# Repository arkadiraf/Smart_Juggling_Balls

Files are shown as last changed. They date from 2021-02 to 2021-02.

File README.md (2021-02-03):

# Smart Juggling Balls
Smart Juggling Balls is a project of mine which consists of 3 basic modules: 
arduino pro mini (compatible) MPU 6050 and nrf24
and a bunch of LEDS of course :)
The files I publish include the PCB manufacturing Gerber files
STL files for the casing (ment for 3d printing)
and some code I wrote.
The idea is to have colorful and happy juggling balls which can change lightning based on the sensor readings 
and remote maniputations communicating via nrf24.

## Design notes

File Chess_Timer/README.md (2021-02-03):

# Chess Timer
Wireless chess clock, Who needs buttons when you can shake a ball :)
More info is available at: https://hackaday.io/project/7430-chess-timer
Video: https://youtu.be/bdC0Rcd7P3E

<br /><span xmlns:dct="http://purl.org/dc/terms/" property="dct:title">Chess_Timer</span> is licensed under a <a rel="license" href="http://creativecommons.org/licenses/by-nc-sa/4.0/">Creative Commons Attribution-NonCommercial-ShareAlike 4.0 International License</a>.

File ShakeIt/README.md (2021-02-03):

# ShakeIt
Shake It is an interactive art exhibition, which is based on my Smart juggling balls and a 3d printed lamp stand filled with LED`s. Shake It was developed for the Jerusalem mini maker faire. The art exhibition is intended to demonstrate light color mixing to children and then reward them with an interactive light game. 

<br /><span xmlns:dct="http://purl.org/dc/terms/" property="dct:title">ShakeIt</span> is licensed under a <a rel="license" href="http://creativecommons.org/licenses/by-nc-sa/4.0/">Creative Commons Attribution-NonCommercial-ShareAlike 4.0 International License</a>.

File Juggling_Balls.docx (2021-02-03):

Smart Juggling Balls: https://youtu.be/MuF92wXwjuk

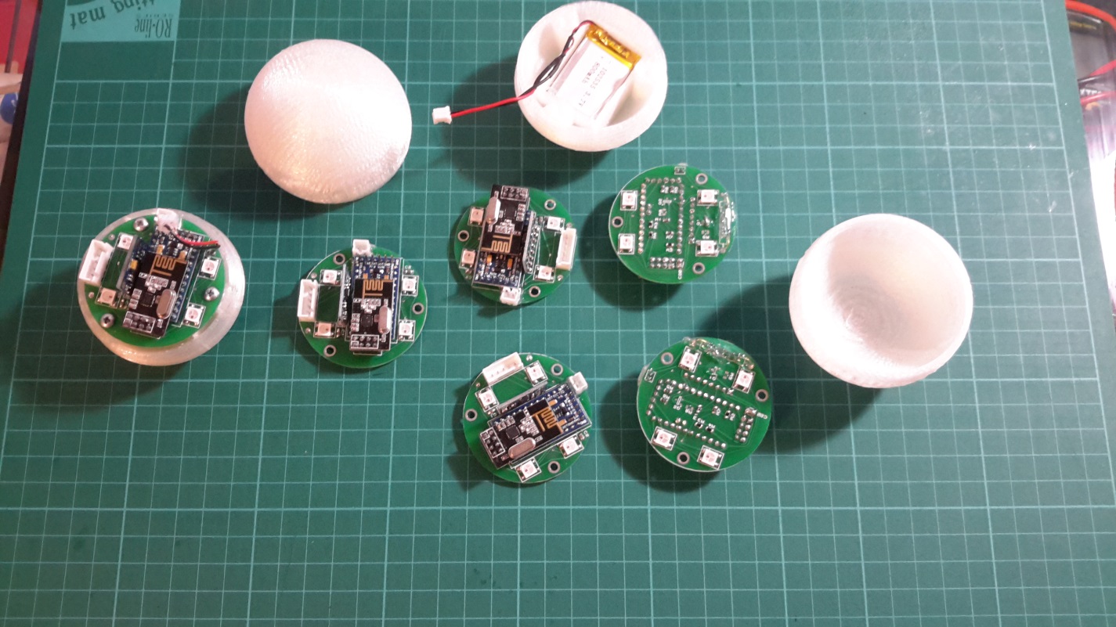
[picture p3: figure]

This is my version for smart juggling balls, the files I share include PCB Circuit manufacture files (Gerber)

STL models for the casing, and codes (currently Test code).

It is possible to assemble the juggling balls using a prototype PCB such as: https://www.sparkfun.com/products/8810 my first iterations were based on the same prototype board and later the PCB was design based on the physical dimensions of the board.

The circuit itself can be ordered from SeeeStudio http://www.seeedstudio.com/service/index.php?r=pcb

Just upload the Attached zip in Circuit→JB_Gerber.zip and order a standard 2 layer pcb. (Schematics are available in Circuit→Juggling_Balls.PDF

STL files for the casing are available in STL→Juggling_Maker_Faire

There are 2 versions one is a bit thicker.

All parts and links are available in Juggling_Balls_Bom.xlsx

Some notes on assembling:

Currently the power circuit (Transistor and mosfet) weren`t tested out,I use a wire to short the mosfet and use the connected pin (D8) as a magnet detector through the reed switch.

In one of the batches the holes for the arduino board came a bit tight so I was required to drill wider and then solder the pins for the arduino model from both sides of the pcb.

The Nrf model pins are needed to be cut a bit and the plastics removed so the NRF model will sit flat on the 2x4 header.

The circuit is design for the arduino compatible models available on ebay, such that the pinout for the FTDI is as in the image: (alternatively it is possible to use a different arduino version without soldering the FTDI headers to the pcb board, in that case the 5 pin connector will not be connected to the board DTR).

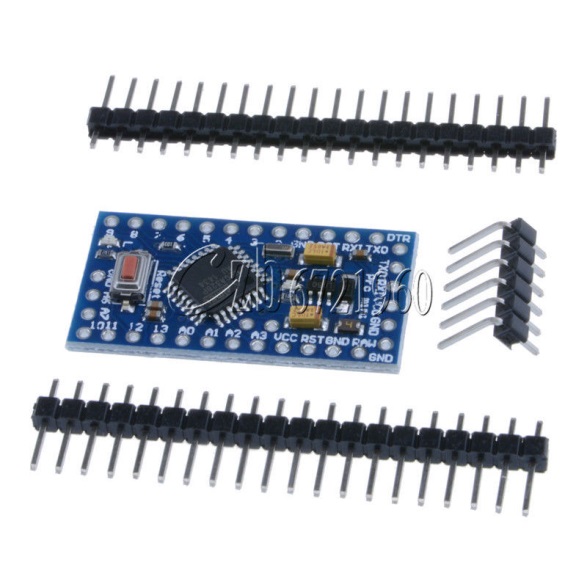
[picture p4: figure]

The direction of the SMD RGB LEDS such that the ‘cut’ corner of the LED first in the small Square drawn on the PCB.

All Resistors and capacitors aren`t Solid science, feel free to make variations, I myself solder a 1 uF capacitor instead the 47 uF and use 10kOhm resistors instead the 47kOhm

Note the correct direction for the Pin headers

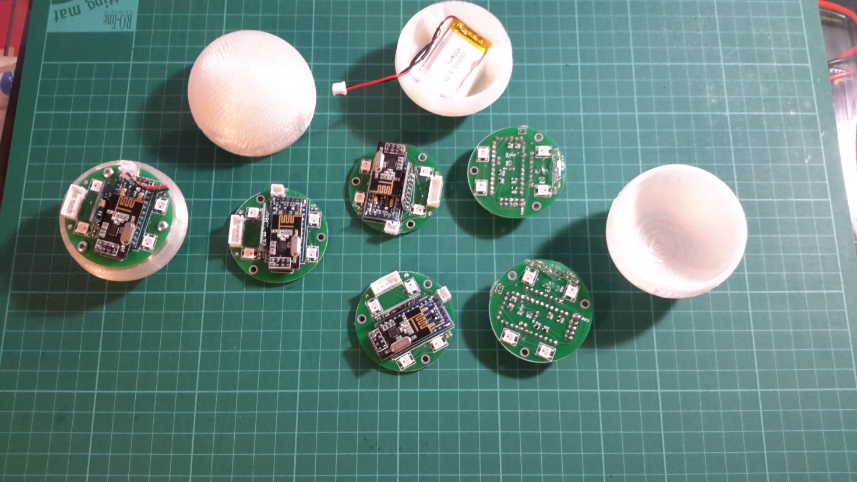
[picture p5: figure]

Enjoy.

Thanks to Eugene: http://techno-mind.ru/ for helping with the initial PCB design for manufacturing.

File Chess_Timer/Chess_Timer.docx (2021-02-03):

Chess Timer (https://hackaday.io/project/7430-chess-timer)

Wireless chess clock, Who needs buttons when you can shake a ball :)

Wirelessly controlled chess clock, to save the motion of pressing a button: you save time, you save energy, and it looks cool... Just kidding.

Recently i have joined a chess club at the google campus meetups, and as fitting for a meetup at the google campus you need to make something different. So figuring that i have already made a cool setup with my "Smart Juggling Balls": (https://hackaday.io/project/5466-smart-juggling-balls), and using the concept of interactive game of my other project, "ShakeIt" (https://hackaday.io/project/6039-shakeit). I have ended up with my current design of a chess clock.

As you can guess already, you shake the ball instead pressing the regular buttons off the clock. And because buying a chess clock just to hack it, is a little expensive i have decided to make my own design of a chess clock. (actually i think hacking a standard chess clock would have been a cheaper setup, but definitely much less cool).

So for my own design i have decided to go for a different time indication by using two digitally addressable LED rings (each ring with 16 pixels). and to wrap it all up ended up with a Lizard`s \ Robot`s Head for the clock, as you can see in the images :).

So basically i have ended up with 2 juggling balls and a lizard`s head, when you shake a ball the opponents time is starting to get down, The amount of LED`s on, indicates how much time is left. and while it is your turn the ball is also colored, RED and Blue for each opponent, and Green for when it`s not your turn. (The video demonstrates it better).

For setting the time, Displaying the exact time left, and other setting`s i am using bluetooth module in the lizard`s head to communicate with a standard smartphone app wich streams data over bluetooth.

All of the sources (Codes, PCB, STL`s) are available on Github and on Thingiverse. You are welcome to make your own wireless chess clock.

Enjoy.

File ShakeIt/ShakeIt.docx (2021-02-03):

# ShakeIt

# Interactive Art Exhibition

ShakeIt is an interactive art exhibition, which is based on my Smart juggling balls and a 3d printed lamp stand filled with LED`s. ShakeIt was developed for the Jerusalem mini maker faire. The art exhibition is intended to demonstrate light color mixing to children and then reward them with an interactive light game.

Operation:

First each kid is handed a smart ball, with a predefined color (Red, Green, Blue) when the ball is shaken (Accelerometer) the light inside the ball becomes stronger (RGB LED`s). The lamp stand is used as a mixer, it communicates with the balls and receives the value of how strong the light inside each of the smart balls mixing them and generating the mixed color.

The kids are then requested to shake the ball in sequence than in pairs generating all sorts of mixes and understanding how light is mixed and what colors are generated from the basic lights (Red, Green, Blue).

After that the participants get to play an interactive game, the game consists the same smart balls, and the light stand, but instead of just mixing the light the stand generates patterns based on how strong the balls are shaken. At first the light is just filling up the stand but then each color starting to eat the next one until only one color remains and the winner is declared. (see video)

Technical information:

The smart juggling balls description can be found here: https://github.com/arkadiraf/Juggling_Balls_Public , or on my Hackaday project page: https://hackaday.io/project/5466-smart-juggling-balls.

The Light stand consists of Arduino nano (compatible), Nrf24L01+ with SMA Antenna, Dc Dc converter to step down from 6-12 volts to 5 volts (meant to be used with external 12V power supply, or 2S lipo battery), Digital Addresable LED`s in a strip of 60 Leds/Meter with a total of 74 LED`s, Bluetooth module HC-05. Some capacitors, 3.3 voltage regulator and a schottky diode3A for reverse voltage protection. The arduino Nano is fed directly from the power supply (through the diode) and the DC DC converter is used for the LED strip. Currently I am using a pcb I designed with traces for the NRF module, Arduino nano (compatible) and the 3.3V regulator, around which I constructed the rest of the circuit). The files of the PCB are available on GitHub. The StL files for the lamp stand are also available on GitHub including both the codes for the smart balls and the lamp.

Notes:

I am using the Accelerometer to measure how strong the ball is shaken by measuring the acceleration and filtering the results with a simple digital LPF Filter with a time constant of a few seconds.

The lamp stand uses the NRF module to communicate with the Smart balls, and the Bluetooth module is used to communicate with a Smartphone using it as an interface and changing the operation modes.

The code for the system is designed to interact with up to 15 Smart balls, starting by scanning which balls are active and then using a simple protocol to communicate with each of the active balls by sending a request for data and waiting for a response.

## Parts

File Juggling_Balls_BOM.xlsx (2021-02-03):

 | Juggling Balls Parts
Item |  | Link
1 circuit PCB or Prototype round PCB: |  | https://www.sparkfun.com/products/8810
Casing (3d Printed) |  | STL Files
Arduino Compatible pro mini |  | http://www.ebay.com/itm/131091305008?_trksid=p2060778.m2749.l2649&ssPageName=STRK%3AMEBIDX%3AIT
MPU 6050 |  | http://www.ebay.com/itm/161267559751?_trksid=p2060778.m2749.l2649&ssPageName=STRK%3AMEBIDX%3AIT
NRF24L01 |  | http://www.ebay.com/itm/140729183185?_trksid=p2060778.m2749.l2649&ssPageName=STRK%3AMEBIDX%3AIT
ReedSwitch |  | http://www.ebay.com/itm/161267559751?_trksid=p2060778.m2749.l2649&ssPageName=STRK%3AMEBIDX%3AIT
Li-Ion Battery |  | http://www.aliexpress.com/snapshot/6526903112.html?orderId=66147013510053
SMD Parts: | SeeedStudio | http://www.seeedstudio.com/depot/OPLopen-parts-library-catalog-c-136_138/?ref=side
WS2812b LED | SKU: 800052001 | http://www.seeedstudio.com/depot/WS2812B-RGB-LED-with-Integrated-Driver-Chip-10-PCs-pack-p-1675.html
Mosfet |  | SMD MOSFET P-CH -8V -4.1A(0440210P1)
Transistor |  | SMD Transistors NPN 25V-500mA(0400000P1)
Resistors |  | SMD RES 10K-5%-1/8W(301010304)
 |  | SMD RES 47K-1%-1/8W(301010388)
 |  | SMD RES 220R-5%-1/8W(301010315
 |  | SMD RES 1K-5%-1/8W(301010311)
Capacitors |  | SMD CAP Ceramic 100nF-50V-10%-X7R;(302010165)
 |  | SMD CAP Ceramic 1uF-25V-10%-X7R(0100440P1)
Connectors |  | DIP JST 2P-2.0(320110049)
DIP JST 5P 2.5 |  | http://www.ebay.com/itm/10-kits-XH2-54mm-5pin-JST-Connector-plug-Male-Female-Crimps-DIP-5P-/331376224432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
DIP 8P 2x4 Female header 2.54 |  | http://www.ebay.com/itm/10PCS-2x4-Pin-8P-2-54mm-Double-Row-Female-Straight-Header-Pitch-Socket-Pin-Strip-/310727244114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
Alternative sensor:
MPU 9150 |  | http://www.ebay.com/itm/161096342893?_trksid=p2060778.m2749.l2649&ssPageName=STRK%3AMEBIDX%3AIT

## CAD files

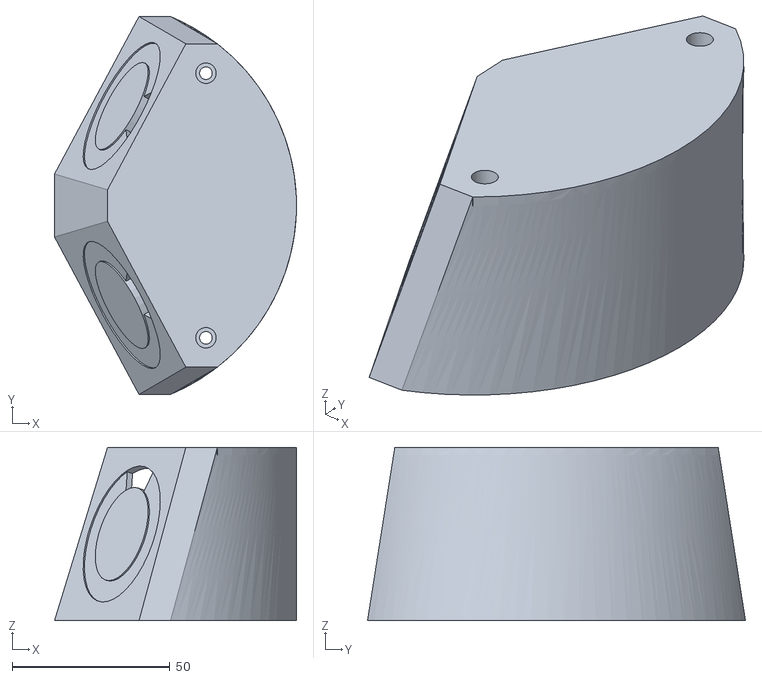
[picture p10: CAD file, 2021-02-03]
Chess_Timer/STL/Timer_Box_1.STL
76.8 x 120.0 x 55.0

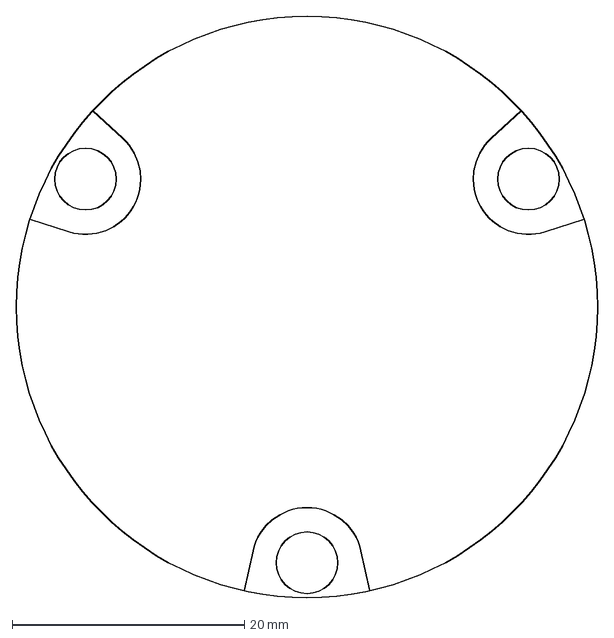
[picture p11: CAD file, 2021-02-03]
Electronics/EduBall_V1.1 - forgotten version/EduBall_Flex.DXF
50.0 x 50.0 mm

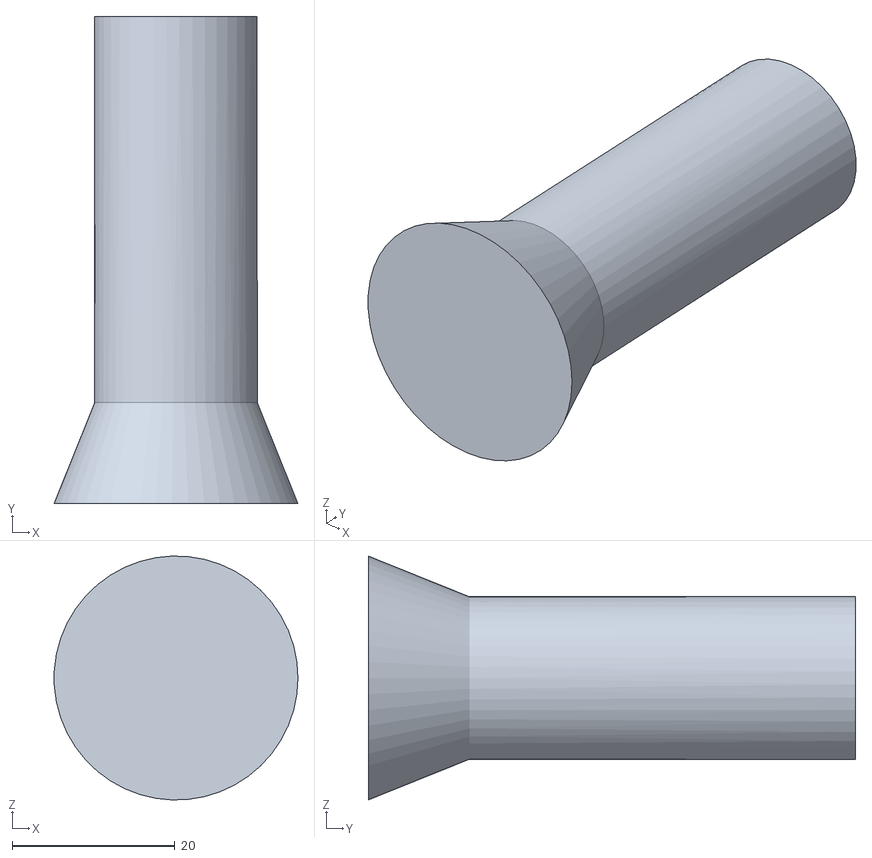
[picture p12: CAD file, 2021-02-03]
ShakeIt/STL/Sensor_Holder.STL
30.0 x 59.9 x 30.0

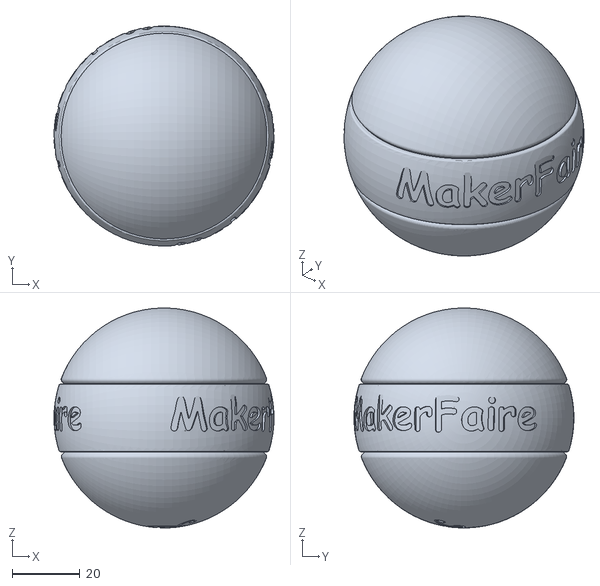
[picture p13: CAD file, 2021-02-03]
STL/Juggling_MakerFaire.STL
65.0 x 65.0 x 64.9

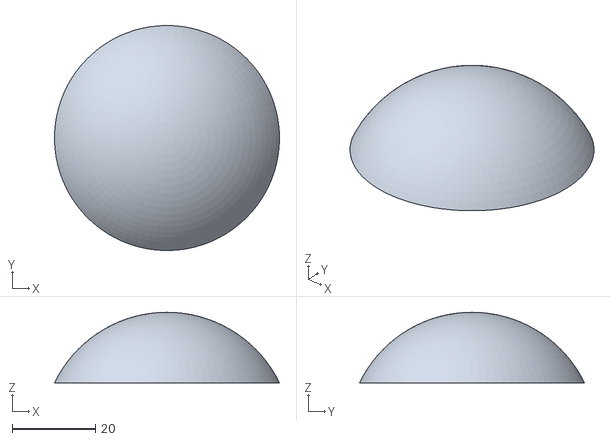
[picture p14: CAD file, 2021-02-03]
Chess_Timer/STL/Eye_Cover_Flat.stl
54.0 x 54.0 x 16.9

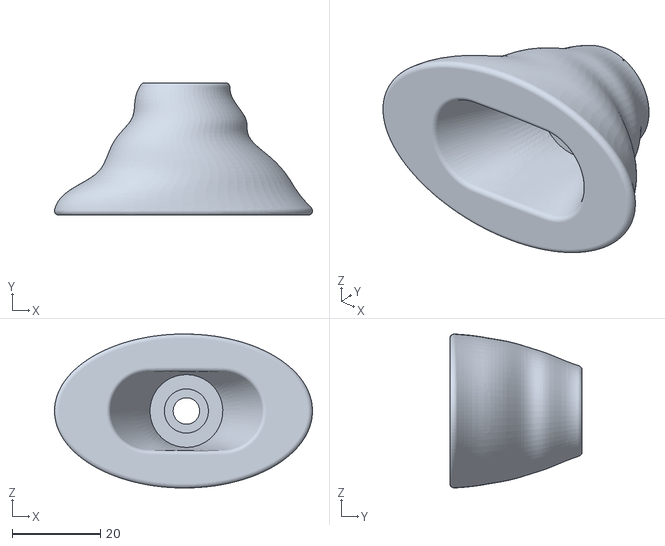
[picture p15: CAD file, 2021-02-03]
ShakeIt/STL/Magnet_Stand.STL
58.4 x 30.0 x 34.9

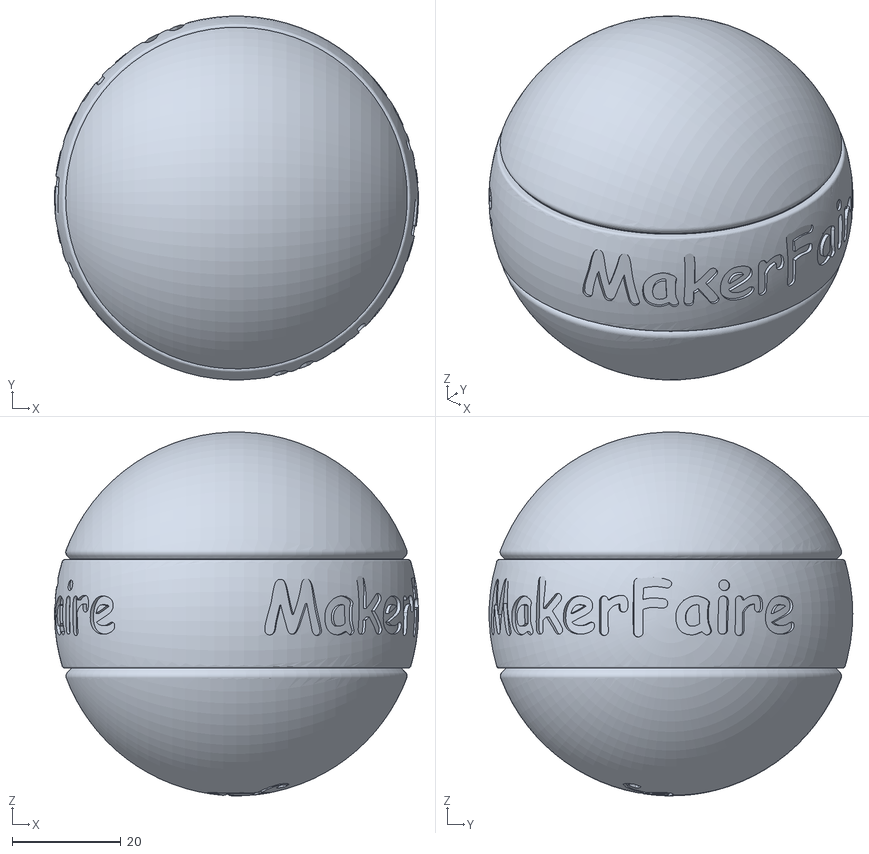
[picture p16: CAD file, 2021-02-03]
STL/Juggling_2_MakerFaire.STL
67.0 x 66.9 x 66.9

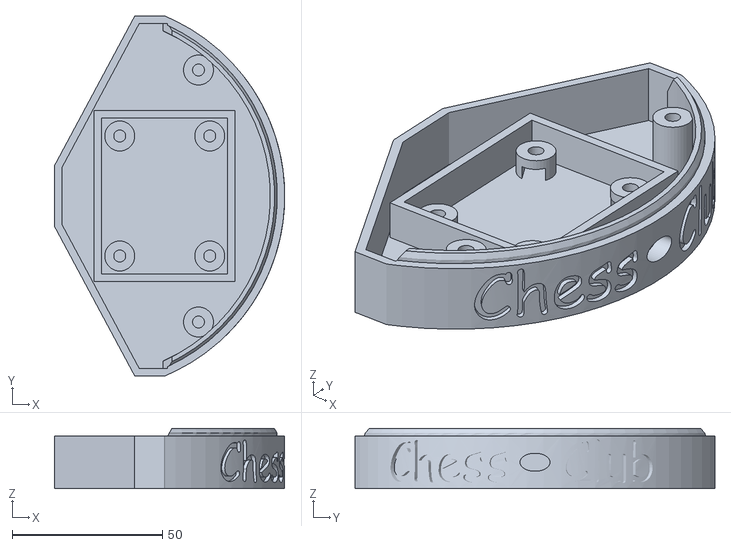
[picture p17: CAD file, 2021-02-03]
Chess_Timer/STL/Timer_Box_2.STL
76.8 x 120.0 x 20.0

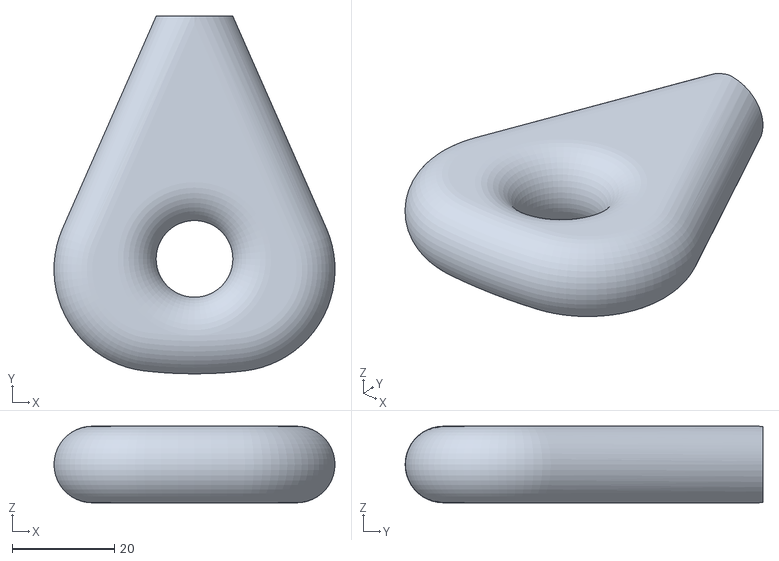
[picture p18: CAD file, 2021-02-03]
ShakeIt/STL/Magnet_Holder.STL
55.0 x 70.0 x 15.0

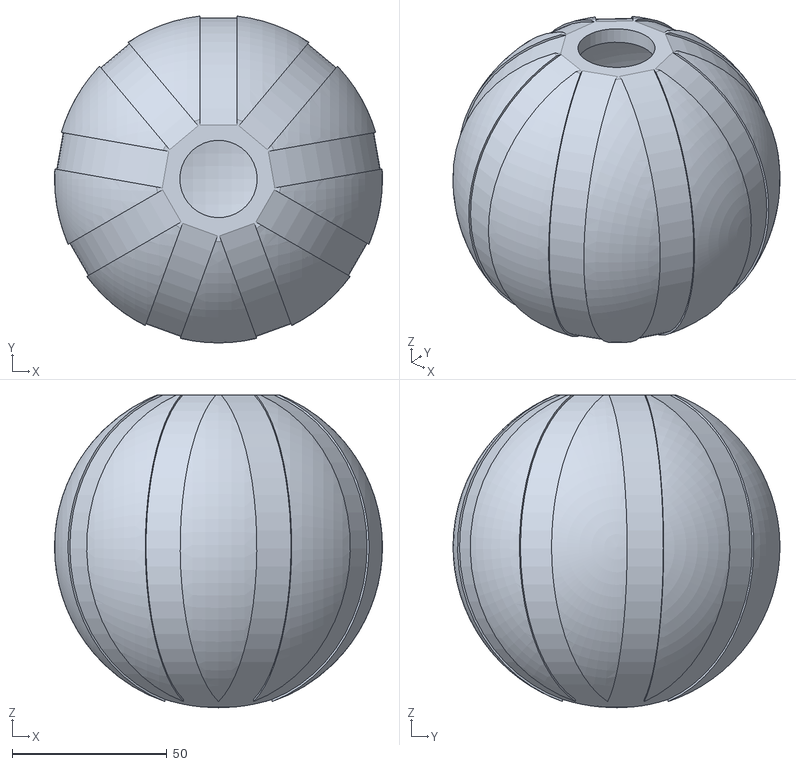
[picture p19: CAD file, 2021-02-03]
ShakeIt/STL/Led_Lamp.STL
106.0 x 105.6 x 101.0

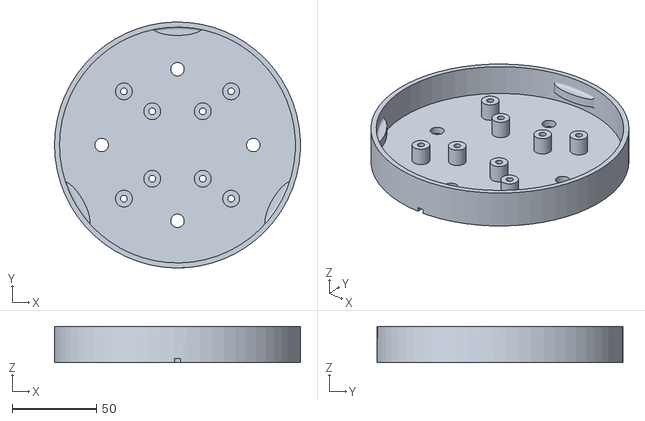
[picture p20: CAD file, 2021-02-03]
ShakeIt/STL/Lamp_Base.STL
146.0 x 146.0 x 21.5

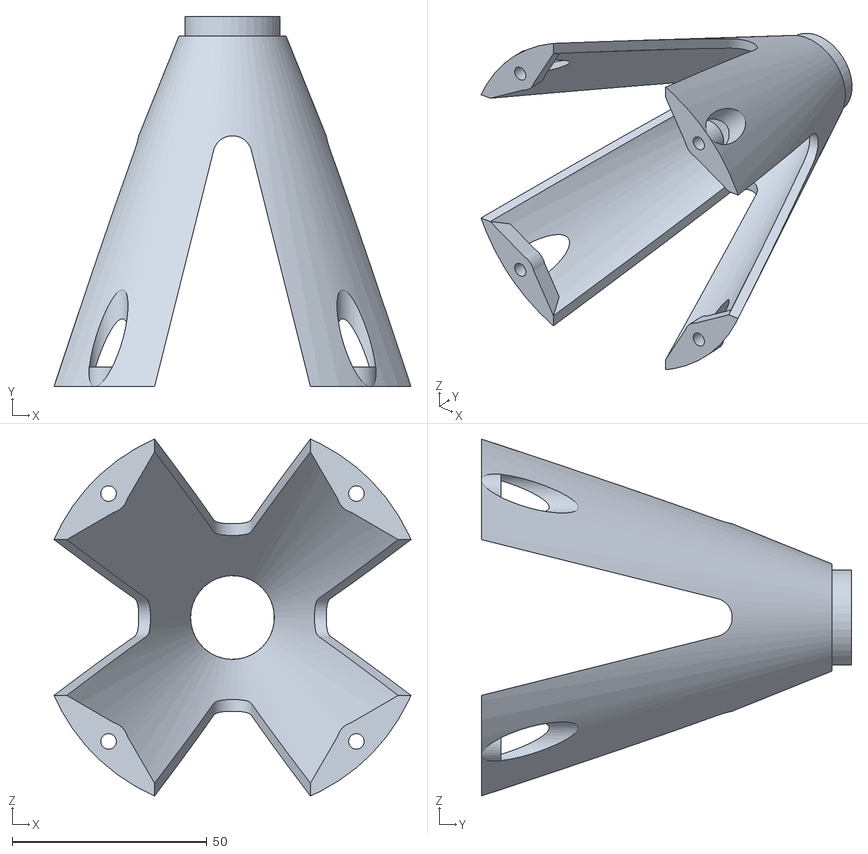
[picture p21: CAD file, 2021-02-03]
ShakeIt/STL/Lamp_Holder.STL
91.7 x 95.0 x 91.7

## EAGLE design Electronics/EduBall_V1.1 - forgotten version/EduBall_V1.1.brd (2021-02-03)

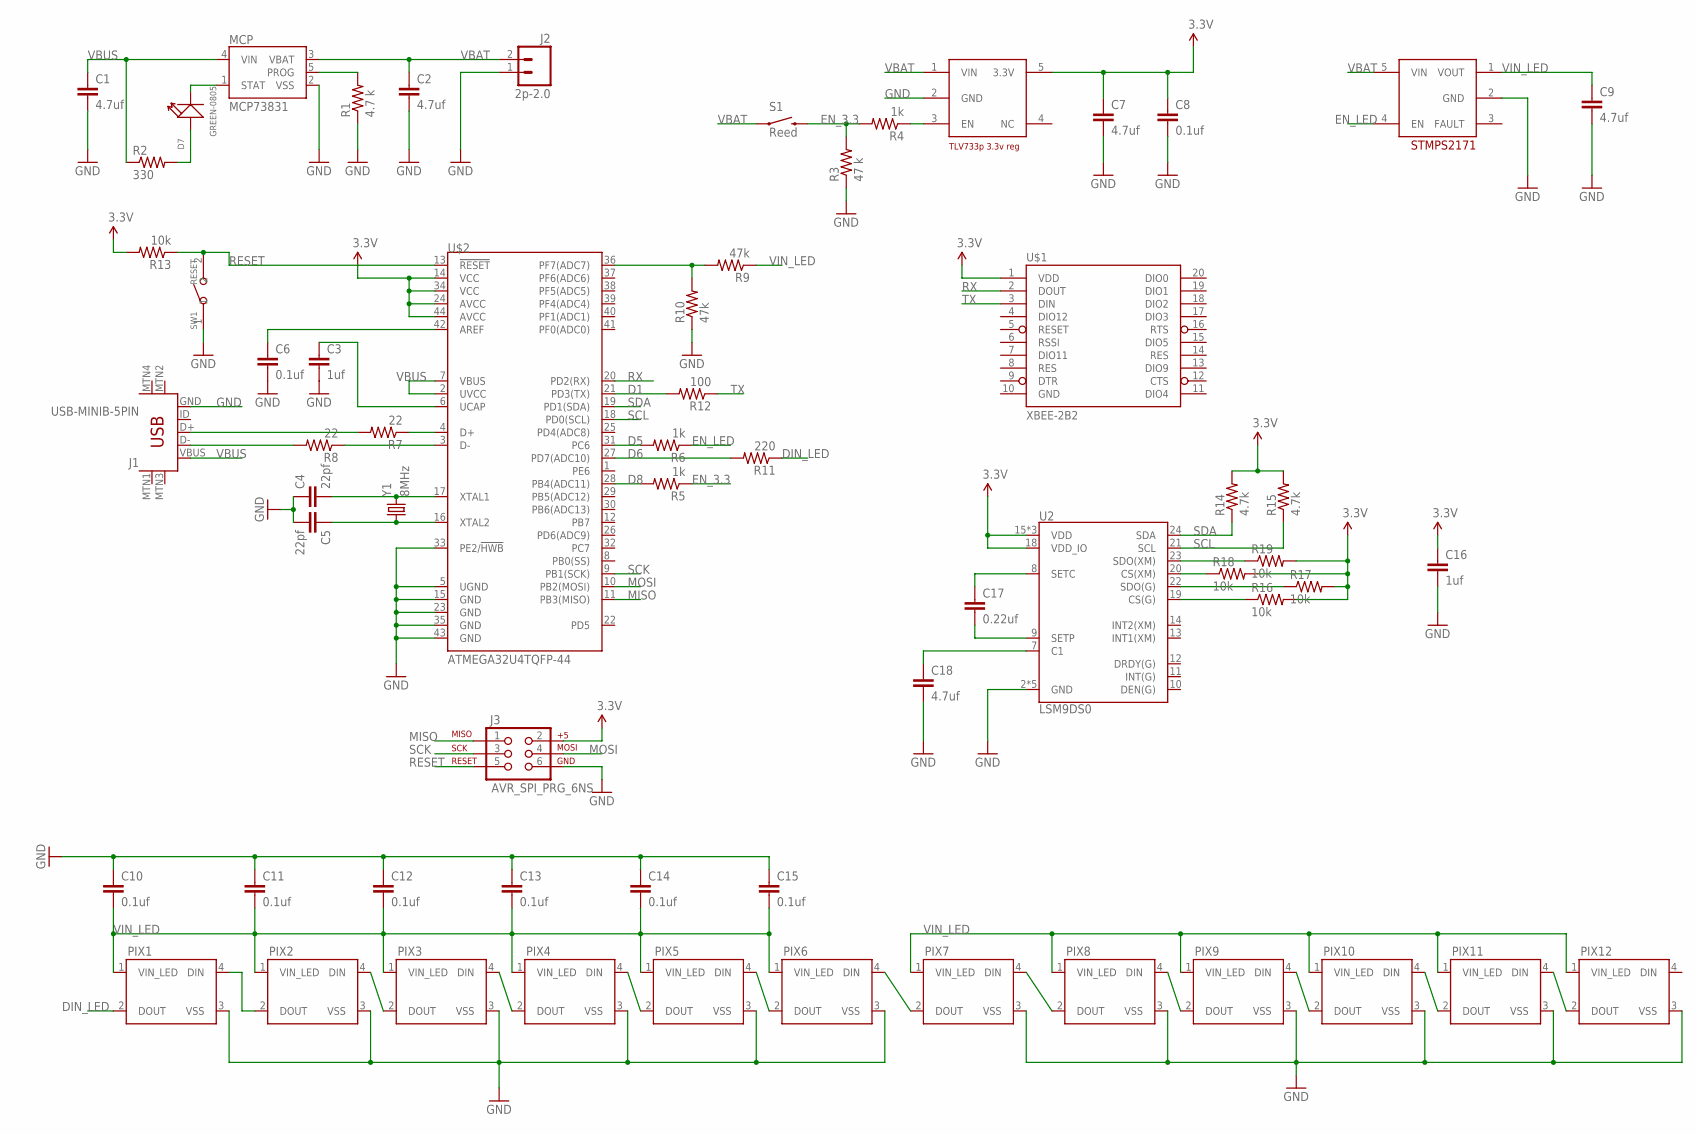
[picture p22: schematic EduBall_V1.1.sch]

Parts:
C1, C2, C7, C9, C18: 4.7uf; 0805
C3, C16: 1uf; 0805
C4, C5: 22pf; 0805
C6, C8, C10, C11, C12, C13, C14, C15: 0.1uf; 0805
C17: 0.22uf; 0805
D7: GREEN-0805; LED-0805
J1: USB-MINIB-5PIN; USB-MINIB
J2: 2p-2.0; JST-2-PTH-VERT
J3: AVR_SPI_PRG_6NS; 2X3-NS
MCP: MCP73831; SOT23-5
PIX1, PIX2, PIX3, PIX4, PIX5, PIX6, PIX7, PIX8, PIX9, PIX10, PIX11, PIX12: WS2812B
R1: 4.7 k; 0805
R2: 330; 0805
R3: 47 k; 0805
R4, R5, R6: 1k; 0805
R7, R8: 22; 0805
R9, R10: 47k; 0805
R11: 220; 0805
R12: 100; 0805
R13, R16, R17, R18, R19: 10k; 0805
R14, R15: 4.7k; 0805
S1: Reed; REED_SWITCH_PTH
STMP: STMPS2171; SOT23-5
SW1: RESET; SW2-2.6-3.0X2.5X1.2+0.4MM
TLV: TLV3333P; SOT23-5
U2: LSM9DS0; LGA-24
U$1: XBEE-2B2; XBEE-SILK
U$2: ATMEGA32U4TQFP-44; TQFP44
Y1: 8MHz; HC49US

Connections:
3.3V: C7.1, C8.1, C16.1, J3.2, R13.2, R14.2, R15.2, R16.2, R17.2, R18.2, R19.2, TLV.5 (3.3V), U2.15 (VDD), U2.16 (VDD), U2.17 (VDD), U2.18 (VDD_IO), U$1.1 (VDD), U$2.14 (VCC), U$2.24 (AVCC), U$2.34 (VCC), U$2.44 (AVCC)
D1: R12.2, U$2.21 (PD3(TX))
D5: R6.2, U$2.31 (PC6)
D6: R11.2, U$2.27 (PD7(ADC10))
D8: R5.2, U$2.28 (PB4(ADC11))
DIN_LED: PIX1.2 (DOUT), R11.1
EN_3.3: R3.2, R4.2, R5.1, S1.P$2 (2)
EN_LED: R6.1, STMP.4 (EN)
GND: C1.2, C2.2, C3.2, C4.1, C5.2, C6.2, C7.2, C8.2, C9.2, C10.1, C11.1, C12.1, C13.1, C14.1, C15.1, C16.2, C18.2, J1.GND, J2.1, J3.6, MCP.2 (VSS), PIX1.3 (VSS), PIX2.3 (VSS), PIX3.3 (VSS), PIX4.3 (VSS), PIX5.3 (VSS), PIX6.3 (VSS), PIX7.3 (VSS), PIX8.3 (VSS), PIX9.3 (VSS), PIX10.3 (VSS), PIX11.3 (VSS), PIX12.3 (VSS), R1.1, R3.1, R10.1, STMP.2 (GND), SW1.1, TLV.2 (GND), U2.2 (GND), U2.3 (GND), U2.4 (GND), U2.5 (GND), U2.6 (GND), U$1.10 (GND), U$2.5 (UGND), U$2.15 (GND), U$2.23 (GND), U$2.33 (PE2/!HWB), U$2.35 (GND), U$2.43 (GND)
MISO: J3.1, U$2.11 (PB3(MISO))
MOSI: J3.4, U$2.10 (PB2(MOSI))
unnamed: MCP.5 (PROG), R1.2
unnamed: PIX1.4 (DIN), PIX2.2 (DOUT)
unnamed: R4.1, TLV.3 (EN)
unnamed: D7.-, MCP.1 (STAT)
unnamed: D7.+, R2.2
unnamed: PIX2.4 (DIN), PIX3.2 (DOUT)
unnamed: PIX3.4 (DIN), PIX4.2 (DOUT)
unnamed: PIX4.4 (DIN), PIX5.2 (DOUT)
unnamed: PIX5.4 (DIN), PIX6.2 (DOUT)
unnamed: PIX6.4 (DIN), PIX7.2 (DOUT)
unnamed: PIX7.4 (DIN), PIX8.2 (DOUT)
unnamed: PIX8.4 (DIN), PIX9.2 (DOUT)
unnamed: PIX9.4 (DIN), PIX10.2 (DOUT)
unnamed: PIX10.4 (DIN), PIX11.2 (DOUT)
unnamed: PIX11.4 (DIN), PIX12.2 (DOUT)
unnamed: J1.D+, R7.2
unnamed: R7.1, U$2.4 (D+)
unnamed: R8.1, U$2.3 (D-)
unnamed: J1.D-, R8.2
unnamed: C3.1, U$2.6 (UCAP)
unnamed: C6.1, U$2.42 (AREF)
unnamed: C18.1, U2.7 (C1)
unnamed: C4.2, U$2.17 (XTAL1), Y1.2
unnamed: C5.1, U$2.16 (XTAL2), Y1.1
unnamed: R9.2, R10.2, U$2.36 (PF7(ADC7))
unnamed: C17.2, U2.9 (SETP)
unnamed: C17.1, U2.8 (SETC)
unnamed: R19.1, U2.23 (SDO(XM))
unnamed: R18.1, U2.20 (CS(XM))
unnamed: R17.1, U2.22 (SDO(G))
unnamed: R16.1, U2.19 (CS(G))
RESET: J3.5, R13.1, SW1.2, U$2.13 (!RESET)
RX: U$1.2 (DOUT), U$2.20 (PD2(RX))
SCK: J3.3, U$2.9 (PB1(SCK))
SCL: R15.1, U2.21 (SCL), U$2.18 (PD0(SCL))
SDA: R14.1, U2.24 (SDA), U$2.19 (PD1(SDA))
TX: R12.1, U$1.3 (DIN)
VBAT: C2.1, J2.2, MCP.3 (VBAT), S1.P$1 (1), STMP.5 (VIN), TLV.1 (VIN)
VBUS: C1.1, J1.VBUS, MCP.4 (VIN), R2.1, U$2.2 (UVCC), U$2.7 (VBUS)
VIN_LED: C9.1, C10.2, C11.2, C12.2, C13.2, C14.2, C15.2, PIX1.1 (VIN_LED), PIX2.1 (VIN_LED), PIX3.1 (VIN_LED), PIX4.1 (VIN_LED), PIX5.1 (VIN_LED), PIX6.1 (VIN_LED), PIX7.1 (VIN_LED), PIX8.1 (VIN_LED), PIX9.1 (VIN_LED), PIX10.1 (VIN_LED), PIX11.1 (VIN_LED), PIX12.1 (VIN_LED), R9.1, STMP.1 (VOUT)

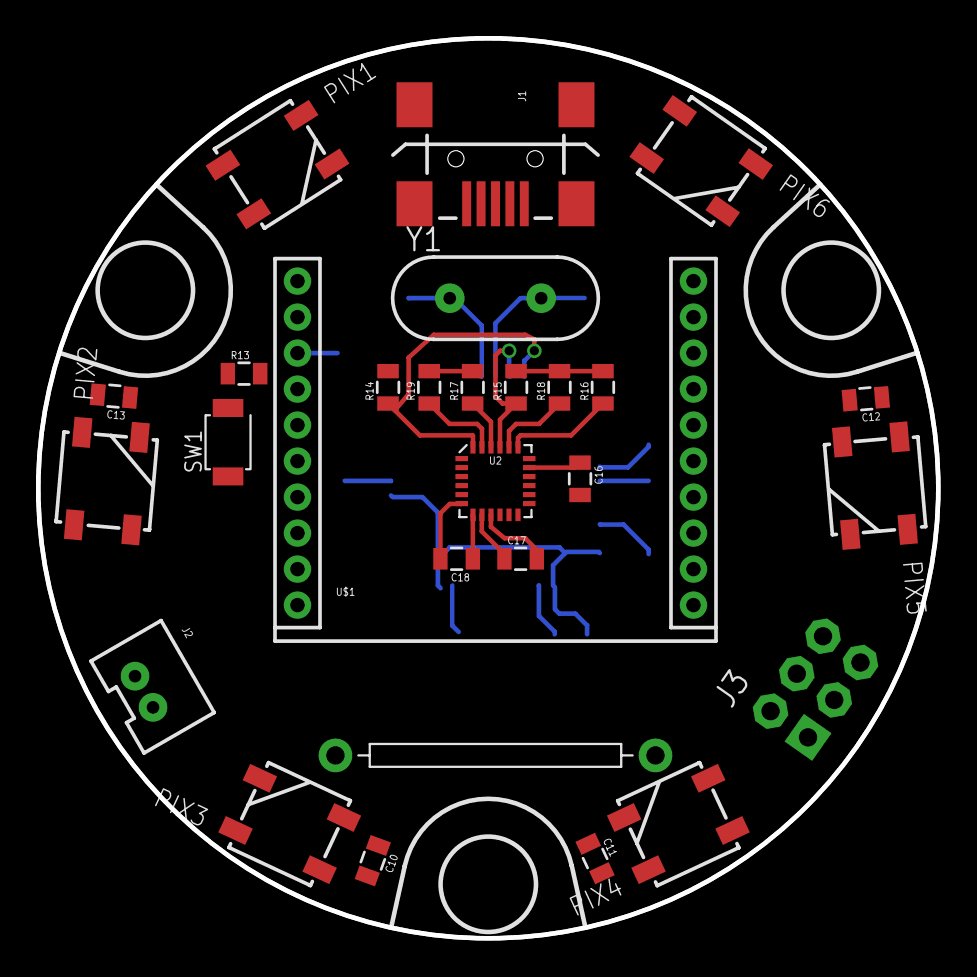
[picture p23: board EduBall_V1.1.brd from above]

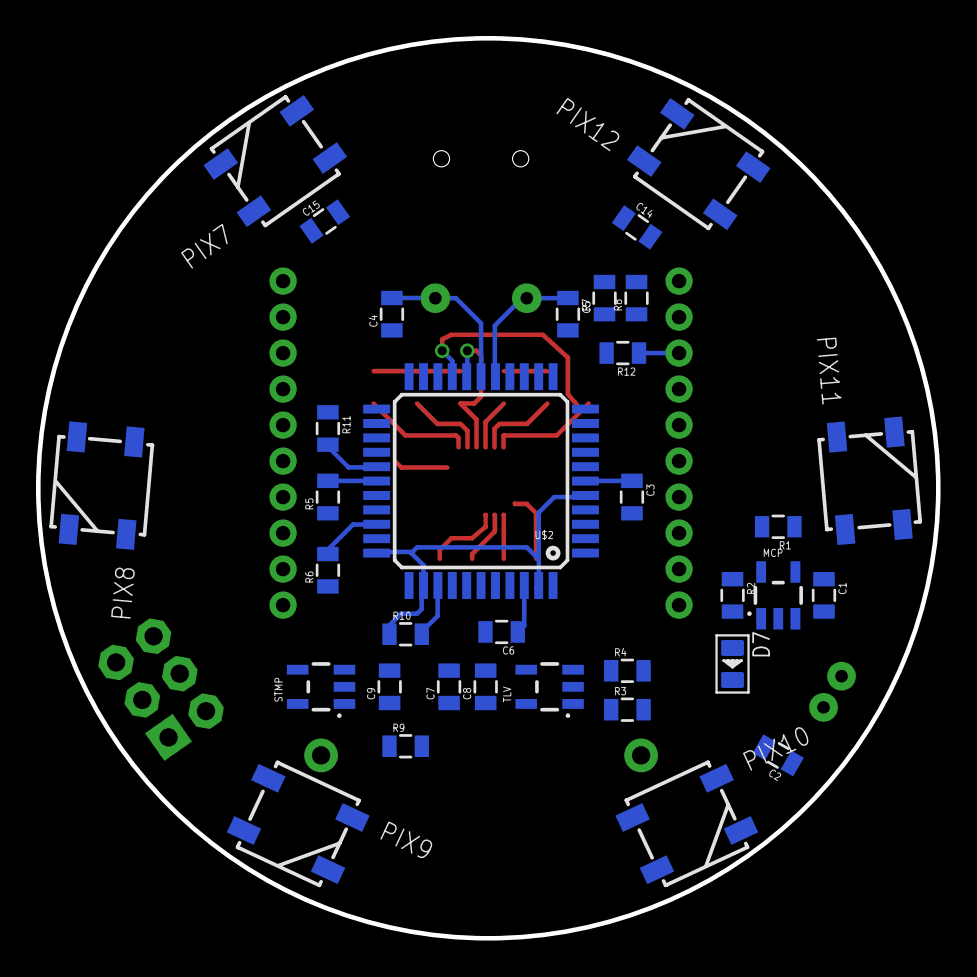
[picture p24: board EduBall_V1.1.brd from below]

Board: 2 copper layers, 50.0 x 50.0 mm, 62 parts (34 on the bottom side), 51 nets.

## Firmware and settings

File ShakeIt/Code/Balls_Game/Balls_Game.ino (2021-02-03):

// Balls_Game 21/05/2015 1:20

/* Pinout:
    Arduino 3.3V:
    A5 (SCL)-->SCL
    A4 (SDA)-->SDA
    D2-->INT DRDYG
    
    D8-->Reed Switch
    
    D6-->NeoPIxel DataIn
    
    A0-->Vraw/2
    
    D9-->CE NRF
    D10-->CSN NRF
    D13 (SCK)-->SCK NRF
    D11 (MOSI)-->MOSI NRF
    D12 (MISO)-->MISO NRF
    D3-->IRQ
    
    connector:
    Vcc--> baterry Vcc
    Dtr --> directly
    Tx --> through 1k // in order to protect from shorts
    Rx --> through 1k
    Grnd --> battery GRN
*/
#define BallNumber 13
///////////////
// libraries //
///////////////
#include <math.h>
#include <SPI.h>
#include "nRF24L01.h"
#include "RF24.h"
#include <Adafruit_NeoPixel.h>
#include "I2Cdev.h"
#include "MPU6050.h"
#include "Wire.h"

///////////////
// Variables //
///////////////

#define rad2deg 57.295

///////////////
// MPU 6050 //
///////////////

MPU6050 accelgyro;

#define MPUREADDELAY 20
// Single radio pipe address for the 2 nodes to communicate.
unsigned long MpuMillisStamp=0;

const byte INT_MPU_PIN = 2; // INT DRDYG

int16_t ax, ay, az;
int16_t gx, gy, gz;

double AcclValue[3]={0,0,0}; //in G values
double GyroValue[3]={0,0,0}; //in Degrees per second

#define SAMPLE2GACC 2048.0   // +/-16g full scale, 16 bit resolution--> 2^16/32=2048
#define SAMPLE2AGYRO 16.384  // +/-2000 Deg/Sec, 16 but tesolution--> 2^16/4000=16.384
	
////////////////////////////
// communication variable //
////////////////////////////
#define NUMPLAYERS 15
// players addresses
const uint64_t BallsAddresses[NUMPLAYERS] ={0xF3b1b3F5c3LL,0xF3b2b3F5c3LL,0xF3b3b3F5c3LL,0xF3b4b3F5c3LL,0xF3b5b3F5c3LL,0xF3b6b3F5c3LL,0xF3b7b3F5c3LL,0xF3b8b3F5c3LL,0xF3b9b3F5c3LL,0xF3bab3F5c3LL,0xF3bbb3F5c3LL,0xF3bcb3F5c3LL,0xF3bdb3F5c3LL,0xF3beb3F5c3LL,0xF3bfb3F5c3LL};
#define CommunicationDelay 100
// Single radio pipe address for the 2 nodes to communicate.
unsigned long CommunicationMillisStamp=0;

// Set up nRF24L01 radio on SPI bus plus pins 9 & 10
RF24 radio(9,10);
// Radio pipe addresses for the 2 nodes to communicate.
//const uint64_t pipes[2] = { 0xF0F0F0F0E1LL, 0xF0F0F0F0D2LL };
const uint64_t Txpipes[2] ={0xb3F3F3b3b5LL,0xb3F3F3b3b7LL};
const uint64_t Rxpipes =BallsAddresses[BallNumber];
#define NTWIDN 0xF3F3F3

/////////////
// Battery //
/////////////
double Vbaterry=3.7;
#define VBATTERY_PIN A0
#define ADC2VBAT 163.0 // Convert ADC reading to voltage, VBatt*10/57=Vref/ADC_Res Vref=1.1v ADC_Res=1023 
#define BATTERYMINIMUM 3.0 // minimum allowed battery voltage
byte BatteryStatus=1; // variable to indicate battery status,0- empty, 1-full
#define BatterySampleDelay 1000 // sample period of the battery voltage
unsigned long VbatSampleMillis=0; // variable to hold millis counter

////////////////
// Neo Pixels //
////////////////
#define NEOPIXELS 8
#define NEODATAPIN 6
// neo Pixel initialize
Adafruit_NeoPixel strip = Adafruit_NeoPixel(NEOPIXELS, NEODATAPIN, NEO_GRB + NEO_KHZ800);


/////////////////////
// Juggling Status //
/////////////////////

double AcclNorm=0;

#define REEDSWITCHPIN 8
int MagStatus=0;
// define colors array
// [White,Red,Lime,Blue,Yellow,Cyan,Magenta,Maroon,Olive,Green,Purple,Teal,Navy]  from http://www.rapidtables.com/web/color/RGB_Color.htm
#define NUMOFCOLORS 13
uint32_t ColorsArr[NUMOFCOLORS]={0xFFFFFF,0xFF0000,0x00FF00,0x0000FF,0xFFFF00,0x00FFFF,0xFF00FF,0x800000,0x808000,0x008000,0x800080,0x008080,0x000080};
byte CurrColorNum=0;
uint32_t Color=0x000000;
#define ColorBlack 0x000000

// Status based on accelerometer
// 0- free fall, 1- 1G, 2- bump or anything else
byte AcclStatusArr[3]={1,1,1};

// Mode based on Magnetometer
// 0- No Magnet, 1- Magnet,
byte MagStatusArr[3]={1,1,1};
// set pixel state
// 0- do nothing, 1- change color, 2- 1G be green
byte PixelState=0;
#define PixelsNumStates 3 // not in use

// set pixel mode:
// 0- off, 1- all colors the same, 2- chasing one color, 3-chasing 2 colors, 4-6-Game Mode
byte PixelsMode=0;
#define PixelsNumModes 7
// variable to store pixel referance for theater chasing mode
int theaterChasePixel=0;

unsigned long theaterChaseMillis=0; // timer counter
#define theaterChaseDelay 100

// color update rate
unsigned long ColorUpdate=0;


///////////////
// Game Mode //
///////////////
// variable to define game mode status
byte GameModeSimple=1; // 1- simple game, 0 complex game
#define GAMEMODECOMPLEX 0xF0F0F0
#define GETCOLOR 0xFF00FF
#define WINRED 0xFF0000
#define WINGREEN 0x00FF00
#define WINBLUE 0x0000FF
#define SPARKUP 0xb0b0b0
uint32_t GameColor=0x000000;

// color update rate
unsigned long GameColorUpdate=0;

// color value converter
#define ACC2COLOR  35.0// 8 G is scaled to 255
double ColorGameValue=0;
byte ColorGameByte=0;
// LPF (Low Pass Filter) Coef for Acceleration value
double AcclNormLPF=0;
#define LPFACC 0.98

///////////////
// SETUP	 //
///////////////
void setup(){
      // join I2C bus (I2Cdev library doesn't do this automatically)
    Wire.begin();
    // initialize serial communication
    Serial.begin(57600);
  // neo Pixel initialize
  strip.begin();
  strip.show(); // Initialize all pixels to 'off'
  
  // Nrf initialize
  radio.begin();
  radio.setChannel(79);
  radio.setPALevel(RF24_PA_HIGH);
  radio.setDataRate(RF24_250KBPS);
  radio.setPayloadSize(8);
  radio.setRetries(0,0);
  radio.setAutoAck(false);
  radio.openWritingPipe(Txpipes[0]);
  radio.openReadingPipe(1,Rxpipes);
  radio.startListening();
  
  //MPU6050 Settings
  // initialize device
    accelgyro.initialize();

    // verify connection
    Serial.println(accelgyro.testConnection() ? "MPU6050 connection successful" : "MPU6050 connection failed");

    // change accel/gyro scale values
    // set accelerometer to 16G and gyro to 2000 deg/sec
    accelgyro.setFullScaleAccelRange(MPU6050_ACCEL_FS_16);
    accelgyro.setFullScaleGyroRange(MPU6050_GYRO_FS_2000);
  
  // set battery pin as input  with internal referense of 1.1v and read voltage
  analogReference(INTERNAL);
  delay(10);// settle down
  pinMode(VBATTERY_PIN, INPUT);
  Vbaterry=((double)analogRead(VBATTERY_PIN))/ADC2VBAT;
  
  // Set pin modes
  pinMode(REEDSWITCHPIN, INPUT);
  // interrupt pins
  pinMode(2, INPUT);
  pinMode(3, INPUT);

}

///////////////
// MAIN LOOP //
///////////////
void loop(){
  //Serial.println(millis());
	
	// update battery voltage
	if ((millis()-VbatSampleMillis)>BatterySampleDelay){
		VbatSampleMillis=millis();
		Vbaterry=((double)analogRead(VBATTERY_PIN))/ADC2VBAT;
		if (Vbaterry>(BATTERYMINIMUM+0.1)){ //add 0.1 in order to remove turning on and off when battery close to value.
			BatteryStatus=1;
		}else if (Vbaterry<BATTERYMINIMUM){
			BatteryStatus=0;
		}
		//Serial.println(Vbaterry);
	}
	 // accelerometer interrupt ready
	 if ((millis()-MpuMillisStamp)>MPUREADDELAY){
                MpuMillisStamp=millis();
                // read raw accel/gyro measurements from device
                accelgyro.getMotion6(&ax, &ay, &az, &gx, &gy, &gz);
                AcclValue[0]=((double)ax)/SAMPLE2GACC;
                AcclValue[1]=((double)ay)/SAMPLE2GACC;
                AcclValue[2]=((double)az)/SAMPLE2GACC;
                
		AcclNorm=AcclValue[0]*AcclValue[0]+AcclValue[1]*AcclValue[1]+AcclValue[2]*AcclValue[2];
		AcclNorm=sqrt(AcclNorm);

                // calculate LPF value of the acceleration
                AcclNormLPF=AcclNormLPF*(LPFACC) + (AcclNorm-1)*(1-LPFACC); // normalized without gravity (more or less).
                
                // Calculate Color Game Value
                ColorGameValue=(AcclNormLPF*ACC2COLOR);
                if (ColorGameValue>255){ // set max value
                  ColorGameByte=255;
                }else if (ColorGameValue<5){ // set threshhold value
                  ColorGameByte=5;
                }else{
                 ColorGameByte=(byte)ColorGameValue;
                }
                
		// update accelerometer status
		for (int ii=2; ii>0; ii--){
			AcclStatusArr[ii]=AcclStatusArr[ii-1];
		}
		if (AcclNorm<0.4){
			AcclStatusArr[0]=0;	// free fall
		} else if(AcclNorm<1.5){
			AcclStatusArr[0]=1;	// Gravity
		}else{
			AcclStatusArr[0]=2;	// bump or anything else
		}
		
		// change color based on start of free fall
		if (AcclStatusArr[0]==0){
			if (AcclStatusArr[1]==0){
				if (AcclStatusArr[2]!=0){
					PixelState=1; //change color
				}
			}
		}
		
		// One color when in hand
		if (AcclStatusArr[0]==1){
			if (AcclStatusArr[1]==1){
				if (AcclStatusArr[2]==1){
					PixelState=2; //Set color
				}
			}
		}
		
		//Serial.print("A: ");
		//// millis
		//Serial.print(millis());
		//Serial.print(", ");
		//// Using the calcAccel helper function, we can get the
		//// accelerometer readings in g's.
		//Serial.print(AcclValue[0],4);
		//Serial.print(", ");
		//Serial.print(AcclValue[1],4);
		//Serial.print(", ");
		//Serial.println(AcclValue[2],4);
		
		//Serial.println(AcclStatus);


            	// update ReedSwitch status
                MagStatus=digitalRead(REEDSWITCHPIN);
            
		for (int ii=2; ii>0; ii--){
			MagStatusArr[ii]=MagStatusArr[ii-1];
		}
                MagStatusArr[0]=MagStatus;
		
		if ((MagStatusArr[0])&&(MagStatusArr[1])&&(!MagStatusArr[2])){ // magnet detected, switch between modes
			PixelsMode++;
			PixelsMode=PixelsMode%PixelsNumModes;
		}

	
	}
 
  
  
  
        // simple game mode
        if (GameModeSimple){
            unsigned long TimeMillis=millis();
          if (((TimeMillis-CommunicationMillisStamp)>CommunicationDelay)||(CommunicationMillisStamp>TimeMillis)){
            CommunicationMillisStamp=TimeMillis;
            radio.stopListening(); 
            if ((PixelsMode==4)||(PixelsMode==5)||(PixelsMode==6)){ // game modes
            uint32_t WritePacket[2]={NTWIDN,GameColor};
            radio.write( &WritePacket, sizeof(uint32_t)*2 );
            Serial.println(GameColor,HEX);
            }
            radio.startListening();    
            
          }
        }
        //check available data:
        if (radio.available()){
          uint32_t RcvPacket[2]={0,0};
            while (!radio.read( &RcvPacket, sizeof(uint32_t)*2 )); // empty buffer
            if (RcvPacket[0]==NTWIDN){
              if (RcvPacket[1]==GAMEMODECOMPLEX){
                radio.stopListening(); 
                if (GameModeSimple){  // change writing pipe, to complex game pipe
                radio.openWritingPipe(Txpipes[1]);
                GameModeSimple=0;
                }
                //delay(1);
                uint32_t WritePacket[2]={NTWIDN,GAMEMODECOMPLEX}; // send Ack
                radio.write( &WritePacket, sizeof(uint32_t)*2 );
                radio.startListening();
              }else if ((RcvPacket[1]==GETCOLOR)&&(!GameModeSimple)){  
                radio.stopListening(); 
                if ((PixelsMode==4)||(PixelsMode==5)||(PixelsMode==6)){ // game modes
                uint32_t WritePacket[2]={NTWIDN,GameColor};
                radio.write( &WritePacket, sizeof(uint32_t)*2 );
                Serial.println(GameColor,HEX);
                }
                radio.startListening(); 
              }else if((RcvPacket[1]==WINRED)&&((PixelsMode==4))){
               colorWipe(WINRED);
               delay(2000);
               rainbow(10);
               colorWipe(WINRED);
               delay(2000);
              }else if((RcvPacket[1]==WINGREEN)&&((PixelsMode==5))){
               colorWipe(WINGREEN);
               delay(2000);
               rainbow(10);
               colorWipe(WINGREEN);
               delay(2000);
              }else if((RcvPacket[1]==WINBLUE)&&((PixelsMode==6))){
               colorWipe(WINBLUE);
               delay(2000);
               rainbow(10);
               colorWipe(WINBLUE);
               delay(2000);
              }else if(RcvPacket[1]==SPARKUP){
               colorWipe(0xFF0000);
               delay(500);
               colorWipe(0x00FF00);
               delay(500);
               colorWipe(0x0000FF);
               delay(500);
               rainbow(10);
              }
            }
        } 

	// neopixels:
	if((BatteryStatus)&&(PixelsMode)){ //lets play
		
		if (PixelState==1){ //change color
			PixelState=0;
			CurrColorNum++;
			CurrColorNum=CurrColorNum%NUMOFCOLORS;
			Color=ColorsArr[CurrColorNum];
			if (PixelsMode==1){
				colorWipe(Color);
			}
		}
		
		if (PixelState==2){ //be green when in hand
			PixelState=0;
			Color=0x00FF00;
			if (PixelsMode==1){
				colorWipe(Color);
			}
		}
		
		if (PixelsMode==2){
			if ((millis()-theaterChaseMillis)>theaterChaseDelay){
			theaterChaseMillis=millis();
			theaterChase(Color);
			}
		}
		if (PixelsMode==3){
			if ((millis()-theaterChaseMillis)>theaterChaseDelay){
				theaterChaseMillis=millis();
				uint32_t c1=ColorsArr[CurrColorNum] ;
				uint32_t c2=ColorsArr[((CurrColorNum+1)%NUMOFCOLORS)];
				uint32_t c3=ColorsArr[((CurrColorNum+2)%NUMOFCOLORS)];
				theaterChaseMultiColor(c1,c2,c3);
			}
		}
		if (PixelsMode==4){ //game mode
                  if (millis()-GameColorUpdate>100){
                    GameColorUpdate=millis();
                    // update color value
                    GameColor=strip.Color(ColorGameByte,0,0);
                    Serial.print(AcclNormLPF);
                    Serial.print("  ");
                    Serial.println(GameColor,HEX);
                  
                  colorWipe(GameColor);
                  }
		}
		if (PixelsMode==5){ //game mode
                  if (millis()-GameColorUpdate>100){
                    GameColorUpdate=millis();
                    // update color value
                    GameColor=strip.Color(0,ColorGameByte,0);
                    Serial.print(AcclNormLPF);
                    Serial.print("  ");
                    Serial.println(GameColor,HEX);
                  
                  colorWipe(GameColor);
                  }
		}
		if (PixelsMode==6){ //game mode
                  if (millis()-GameColorUpdate>100){
                    GameColorUpdate=millis();
                    // update color value
                    GameColor=strip.Color(0,0,ColorGameByte);
                    Serial.print(AcclNormLPF);
                    Serial.print("  ");
                    Serial.println(GameColor,HEX);
                  
                  colorWipe(GameColor);
                  }
		}
		
		
	}else{	
                if (millis()-ColorUpdate>1000){
                  if (!GameModeSimple){// reset game mode
                    radio.stopListening();
                    radio.openWritingPipe(Txpipes[0]);
                    radio.startListening();
                    GameModeSimple=1; 
                  }
                    ColorUpdate=millis();
                   static byte statetoggle=0;
                   statetoggle++;	
    		//turn pixels off except one
    		for(uint16_t i=0; i<strip.numPixels(); i++) {
    			strip.setPixelColor(i, ColorBlack);
    		}
                  if (statetoggle%2){
    		    strip.setPixelColor(0,0x100000);
                    }
                    else{
                    strip.setPixelColor(0,0x000000);
                    }
    		strip.show();
                }
  
	}			

}// end main



/////////////////////////
// Neo Pixels Functions//
/////////////////////////

// Wipe color Color
void colorWipe(uint32_t c) {
	for(uint16_t i=0; i<strip.numPixels(); i++) {
		strip.setPixelColor(i, c);
	}
	strip.show();
}

//Theatre-style crawling lights.
void theaterChase(uint32_t c) {
	theaterChasePixel++;
	theaterChasePixel=theaterChasePixel%3;
	// set all pixels off
	for (int i=0; i<strip.numPixels();i++){
		strip.setPixelColor(i,ColorBlack);
	}
	//turn every third pixel on starting at the theaterChasePixel
	for (int i=theaterChasePixel; i<strip.numPixels();i=i+3){
		strip.setPixelColor(i, c);    
	}
	strip.show();
}

//Theatre-style crawling lights multi color.
void theaterChaseMultiColor(uint32_t c1, uint32_t c2, uint32_t c3) {
	theaterChasePixel++;
	theaterChasePixel=theaterChasePixel%3;
	// color every third pixel	
	for (int i=0; i<strip.numPixels();i=i+3){ 
		strip.setPixelColor((i+theaterChasePixel)%strip.numPixels(),c1);
	}
	// color every third pixel
	for (int i=0; i<strip.numPixels();i=i+3){
		strip.setPixelColor((i+theaterChasePixel+1)%strip.numPixels(),c2);
	}
	// color every third pixel
	for (int i=0; i<strip.numPixels();i=i+3){
		strip.setPixelColor((i+theaterChasePixel+2)%strip.numPixels(),c3);
	}
	strip.show();
}

void rainbow(uint8_t wait) {
  uint16_t i, j;

  for(j=0; j<256; j++) {
    for(i=0; i<strip.numPixels(); i++) {
      strip.setPixelColor(i, Wheel((i+j) & 255));
    }
    strip.show();
    delay(wait);
  }
}
// Input a value 0 to 255 to get a color value.
// The colours are a transition r - g - b - back to r.
uint32_t Wheel(byte WheelPos) {
  WheelPos = 255 - WheelPos;
  if(WheelPos < 85) {
   return strip.Color(255 - WheelPos * 3, 0, WheelPos * 3);
  } else if(WheelPos < 170) {
    WheelPos -= 85;
   return strip.Color(0, WheelPos * 3, 255 - WheelPos * 3);
  } else {
   WheelPos -= 170;
   return strip.Color(WheelPos * 3, 255 - WheelPos * 3, 0);
  }
}




// calculate heading
float calcHeading(float hx, float hy)
{
	if (hy > 0)
	{
		return 90 - (atan(hx / hy) * 180 / PI);
	}
	else if (hy < 0)
	{
		return 270 - (atan(hx / hy) * 180 / PI);
	}
	else // hy = 0
	{
		if (hx < 0) return 180;
		else return 0;
	}
}

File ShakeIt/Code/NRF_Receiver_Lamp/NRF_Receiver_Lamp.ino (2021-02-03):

// Balls_Game Lamp Station 21/05/15 15:34

/* Pinout:
    Arduino Nano 5V: 
    D6-->NeoPIxel DataIn
    A0-->Vraw/3
  
    D9-->CE NRF
    D10-->CSN NRF
    D13 (SCK)-->SCK NRF
    D11 (MOSI)-->MOSI NRF
    D12 (MISO)-->MISO NRF
    D3-->IRQ
    
    Uart Connected to Bluetooth:
*/
/* TO DO List
 Change WINRED, WINGREEN, WINBLUE commands, when there are many balls, they sometimes light up by mistake.
 when collor is losing turn the balls off so there will be indication that the player lost
 improve scanning for more reliable, not sure where the issues are. maybe charnging channle /  addresses will help.
 The issue with communication is straying messages, add another level of identification, Network,Command, talking module.
 add effects.
 add more games.
 
*/

#include <SPI.h>
#include "nRF24L01.h"
#include "RF24.h"
#include <Adafruit_NeoPixel.h>
#include <stdlib.h> // for the atoi() function

///////////////////////////
// Serial Input Command  //
///////////////////////////
String inputString = "                              ";         // a string to hold incoming data (30 chars length)
boolean stringComplete = false;  // whether the string is complete
int stringCMDStart=-1; // Command String Start
int stringCMDEnd=-1; // Command String Ends
int stringCMDValueStart=-1; // Command Value String Start
int stringCMDValueEnd=-1; // Command Value String Ends

// Split the inputString into Command and Value
String Command="                    "; // The Commands (20 chars length)
String CommandValueString="          "; // The Values (10 chars length)
char CommandValueChar[10]={"         "};
int CommandValue=0; // The Values in Int

byte DataDisp=0;

////////////////////////////
// communication variable //
////////////////////////////
// Set up nRF24L01 radio on SPI bus plus pins 9 & 10
RF24 radio(9,10);

// Radio pipes for Tx and for Rx
//const uint64_t pipes[2] = { 0xF0F0F0F0E1LL, 0xF0F0F0F0D2LL };
//const uint64_t Txpipes =0xF3b3b3F5c3LL;
// define number of players, and their addresses
#define NUMPLAYERS 15
const uint64_t Txpipes[NUMPLAYERS] ={0xF3b1b3F5c3LL,0xF3b2b3F5c3LL,0xF3b3b3F5c3LL,0xF3b4b3F5c3LL,0xF3b5b3F5c3LL,0xF3b6b3F5c3LL,0xF3b7b3F5c3LL,0xF3b8b3F5c3LL,0xF3b9b3F5c3LL,0xF3bab3F5c3LL,0xF3bbb3F5c3LL,0xF3bcb3F5c3LL,0xF3bdb3F5c3LL,0xF3beb3F5c3LL,0xF3bfb3F5c3LL};
const uint64_t Rxpipes[2] ={0xb3F3F3b3b5LL,0xb3F3F3b3b7LL};
byte AvlPlayers[NUMPLAYERS]={0};
// define network identifyer variable
#define NTWIDN 0xF3F3F3
#define GAMEMODECOMPLEX 0xF0F0F0
#define GETCOLOR 0xFF00FF
#define WINRED 0xFF0000
#define WINGREEN 0x00FF00
#define WINBLUE 0x0000FF
#define SPARKUP 0xb0b0b0

/////////////
// Battery //
/////////////
double Vbaterry=7.4;
#define VBATTERY_PIN A0
#define ADC2VBAT 65.4 // Convert ADC reading to voltage, VBatt*4.7/14.7=Vref/ADC_Res Vref=5v ADC_Res=1023 
#define BATTERYMINIMUM 6.0 // minimum allowed battery voltage (2s battery) minus schotkky didoe drop
byte BatteryStatus=1; // variable to indicate battery status,0- empty, 1-full
#define BatterySampleDelay 1000 // sample period of the battery voltage
unsigned long VbatSampleMillis=0; // variable to hold millis counter


////////////////
// Neo Pixels //
////////////////
#define NEOPIXELS 74
#define NEODATAPIN 6
// neo Pixel initialize
Adafruit_NeoPixel strip = Adafruit_NeoPixel(NEOPIXELS, NEODATAPIN, NEO_GRB + NEO_KHZ800);


// [White,Red,Lime,Blue,Yellow,Cyan,Magenta,Maroon,Olive,Green,Purple,Teal,Navy]  from http://www.rapidtables.com/web/color/RGB_Color.htm
#define NUMOFCOLORS 13
uint32_t ColorsArr[NUMOFCOLORS]={0xFFFFFF,0xFF0000,0x00FF00,0x0000FF,0xFFFF00,0x00FFFF,0xFF00FF,0x800000,0x808000,0x008000,0x800080,0x008080,0x000080};
byte CurrColorNum=0;
uint32_t Color=0x000000;
uint32_t ColorMix=0x000000;
#define ColorBlack 0x000000

// declrae RGB Union Type to easily move between fields. 
union ColorTypeUnion
{
  uint32_t RGB;
  uint8_t  CByte[3]; //Blue Green Red
    struct Color
  {
    byte B;
    byte G;
    byte R;  
  }C;
}RGBUnion;

//////////////////  
// Lamp Effects //
//////////////////
// Define Lamp Matrix

#define LAMPRAWS 8
#define LAMPCOLUMNS 9
//uint8_t LampMatrix[LAMPRAWS][LAMPCOLUMNS][3]={0};

//uint8_t LampMatrix[LAMPRAWS][LAMPCOLUMNS][3]={
//{{0x00,0x00,0x00},{0x00,0x00,0x00},{0x00,0x00,0x00},{0x00,0x00,0x00},{0x00,0x00,0x00},{0x00,0x00,0x00},{0x00,0x00,0x00},{0x00,0x00,0x00},{0x00,0x00,0x00}},
//{{0x00,0x00,0x00},{0x00,0x00,0x00},{0x00,0x00,0x00},{0x00,0x00,0x00},{0x00,0x00,0x00},{0x00,0x00,0x00},{0x00,0x00,0x00},{0x00,0x00,0x00},{0x00,0x00,0x00}},
//{{0x00,0x00,0x00},{0x00,0x00,0x00},{0x00,0x00,0x00},{0x00,0x00,0x00},{0x00,0x00,0x00},{0x00,0x00,0x00},{0x00,0x00,0x00},{0x00,0x00,0x00},{0x00,0x00,0x00}},
//{{0x00,0x00,0x00},{0x00,0x00,0x00},{0x00,0x00,0x00},{0x00,0x00,0x00},{0x00,0x00,0x00},{0x00,0x00,0x00},{0x00,0x00,0x00},{0x00,0x00,0x00},{0x00,0x00,0x00}},
//{{0x00,0x00,0x00},{0x00,0x00,0x00},{0x00,0x00,0x00},{0x00,0x00,0x00},{0x00,0x00,0x00},{0x00,0x00,0x00},{0x00,0x00,0x00},{0x00,0x00,0x00},{0x00,0x00,0x00}},
//{{0x00,0x00,0x00},{0x00,0x00,0x00},{0x00,0x00,0x00},{0x00,0x00,0x00},{0x00,0x00,0x00},{0x00,0x00,0x00},{0x00,0x00,0x00},{0x00,0x00,0x00},{0x00,0x00,0x00}},
//{{0x00,0x00,0x00},{0x00,0x00,0x00},{0x00,0x00,0x00},{0x00,0x00,0x00},{0x00,0x00,0x00},{0x00,0x00,0x00},{0x00,0x00,0x00},{0x00,0x00,0x00},{0x00,0x00,0x00}},
//{{0x00,0x00,0x00},{0x00,0x00,0x00},{0x00,0x00,0x00},{0x00,0x00,0x00},{0x00,0x00,0x00},{0x00,0x00,0x00},{0x00,0x00,0x00},{0x00,0x00,0x00},{0x00,0x00,0x00}}
//};

uint8_t LampMatrix[LAMPRAWS][LAMPCOLUMNS][3]={
{{0xFF,0x00,0x00},{0xFF,0x00,0x00},{0xFF,0x00,0x00},{0x00,0xFF,0x00},{0x00,0xFF,0x00},{0x00,0xFF,0x00},{0x00,0x00,0xFF},{0x00,0x00,0xFF},{0x00,0x00,0xFF}},
{{0xFF,0x00,0x00},{0xFF,0x00,0x00},{0xFF,0x00,0x00},{0x00,0xFF,0x00},{0x00,0xFF,0x00},{0x00,0xFF,0x00},{0x00,0x00,0xFF},{0x00,0x00,0xFF},{0x00,0x00,0xFF}},
{{0xFF,0x00,0x00},{0xFF,0x00,0x00},{0xFF,0x00,0x00},{0x00,0xFF,0x00},{0x00,0xFF,0x00},{0x00,0xFF,0x00},{0x00,0x00,0xFF},{0x00,0x00,0xFF},{0x00,0x00,0xFF}},
{{0xFF,0x00,0x00},{0xFF,0x00,0x00},{0xFF,0x00,0x00},{0x00,0xFF,0x00},{0x00,0xFF,0x00},{0x00,0xFF,0x00},{0x00,0x00,0xFF},{0x00,0x00,0xFF},{0x00,0x00,0xFF}},
{{0xFF,0x00,0x00},{0xFF,0x00,0x00},{0xFF,0x00,0x00},{0x00,0xFF,0x00},{0x00,0xFF,0x00},{0x00,0xFF,0x00},{0x00,0x00,0xFF},{0x00,0x00,0xFF},{0x00,0x00,0xFF}},
{{0xFF,0x00,0x00},{0xFF,0x00,0x00},{0xFF,0x00,0x00},{0x00,0xFF,0x00},{0x00,0xFF,0x00},{0x00,0xFF,0x00},{0x00,0x00,0xFF},{0x00,0x00,0xFF},{0x00,0x00,0xFF}},
{{0xFF,0x00,0x00},{0xFF,0x00,0x00},{0xFF,0x00,0x00},{0x00,0xFF,0x00},{0x00,0xFF,0x00},{0x00,0xFF,0x00},{0x00,0x00,0xFF},{0x00,0x00,0xFF},{0x00,0x00,0xFF}},
{{0xFF,0x00,0x00},{0xFF,0x00,0x00},{0xFF,0x00,0x00},{0x00,0xFF,0x00},{0x00,0xFF,0x00},{0x00,0xFF,0x00},{0x00,0x00,0xFF},{0x00,0x00,0xFF},{0x00,0x00,0xFF}}
};

// Union Declaration Matrix
//ColorTypeUnion LampMatrixUnion[LAMPRAWS][LAMPCOLUMNS]={0};

// define Light Mode
// 0 - effects; 1 - simple game; 2 - complex game; other: off
int LightMode=0;
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

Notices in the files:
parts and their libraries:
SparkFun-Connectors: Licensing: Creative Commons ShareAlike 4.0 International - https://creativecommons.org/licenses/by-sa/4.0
